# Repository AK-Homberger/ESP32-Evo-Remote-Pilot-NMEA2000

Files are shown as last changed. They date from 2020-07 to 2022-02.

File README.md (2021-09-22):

# ESP32 Evolution Remote Pilot NMEA2000
This is a Remote Control for an Evolution EV-1 Auto Pilot via NMEA2000 (SeaTalk-NG).

It is based on the work of this project in GitHub: https://github.com/matztam/raymarine-evo-pilot-remote.
Many thanks for all the work to identify the NMEA 2000 codes for the EV-1 Course Computer.

The hardware consists of an ESP32 NodeMCU (here from AZ-Delivery), a CAN bus transceiver, a 433MHz receiver (RXB6) and a power converter.
Thats's all what is required to control an EV-1 based Auto Pilot with a simple 433 MHz remote control.

A standard 4 button 433 MHz KeyFob is used to send (+1 / -1 degree) and (+10 / -10 degrees) course changes to the autopilot (Auto/Standby is optional and requires two more buttons or an additional KeyFob). An accustical feedback for each received key is provided with a piezo buzzer tone. I tried to use the alarm function of the MFD (as within the Seatalk remote control). But so far I was not successful to send any alarm PGN that generates an alarm on the MFD.

For questions/discussions regarding the project you can use the OpenBoatProjects area this [Sailing Forum](https://www.segeln-forum.de/board194-boot-technik/board35-elektrik-und-elektronik/board195-open-boat-projects-org/77895-evo-autopilot-fernbedienung-mit-nmea2000/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). 

It's a German Sailing Forum, but other languages (preferred English) are welcome.

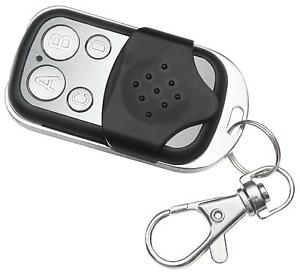
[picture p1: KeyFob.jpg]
KeyFob


The schmatics file and the [pcb details](https://github.com/AK-Homberger/ESP32-Evo-Remote-Pilot-NMEA2000/blob/master/ESP32EvoPilotRemotePCB.pdf) are in the KiCAD folder.
You can simply order a board from aisler.net: https://aisler.net/p/SXWTZTTS

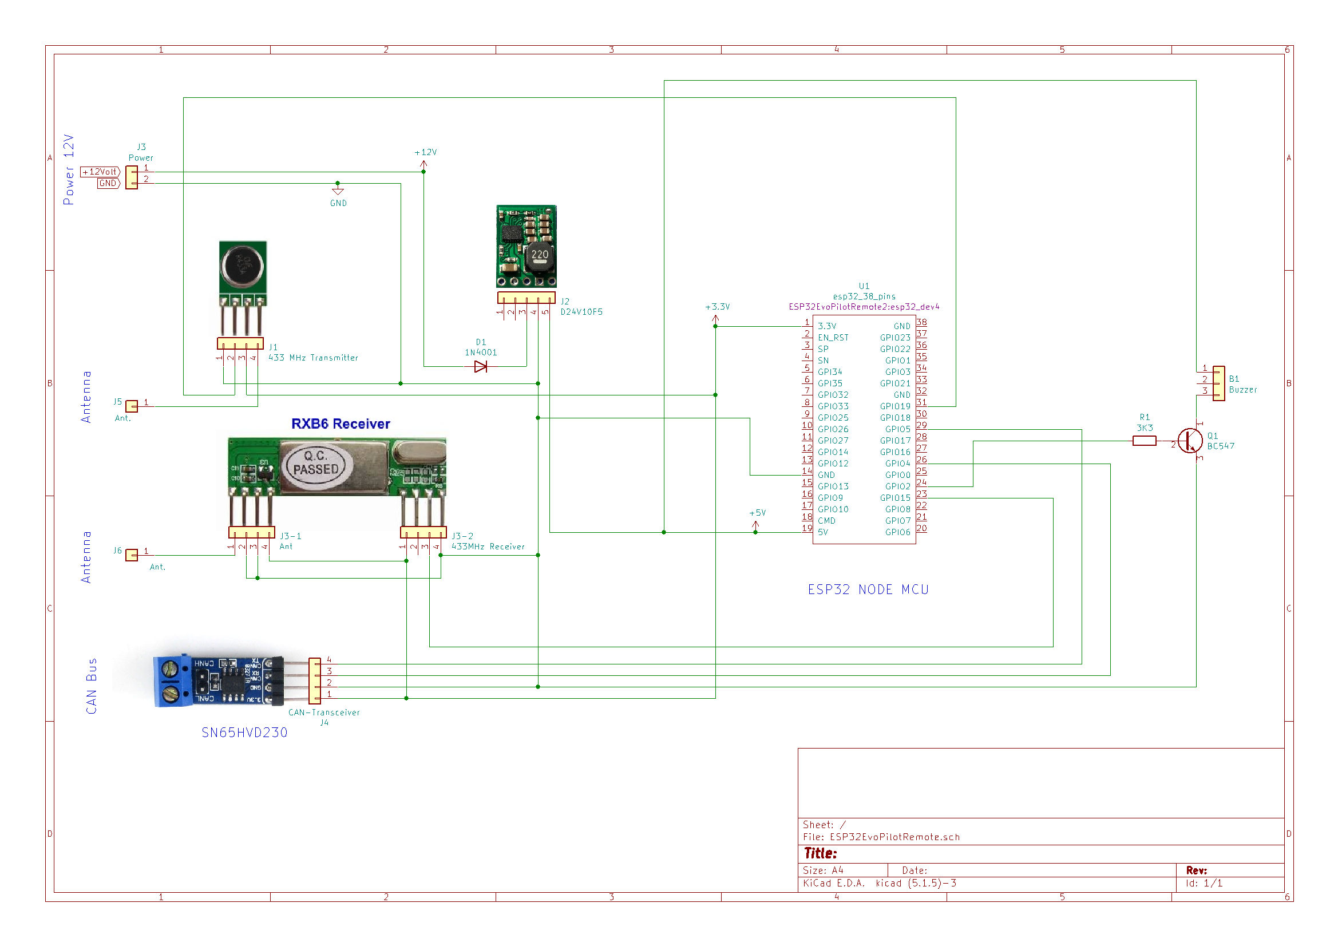
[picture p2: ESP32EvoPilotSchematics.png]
Schematics


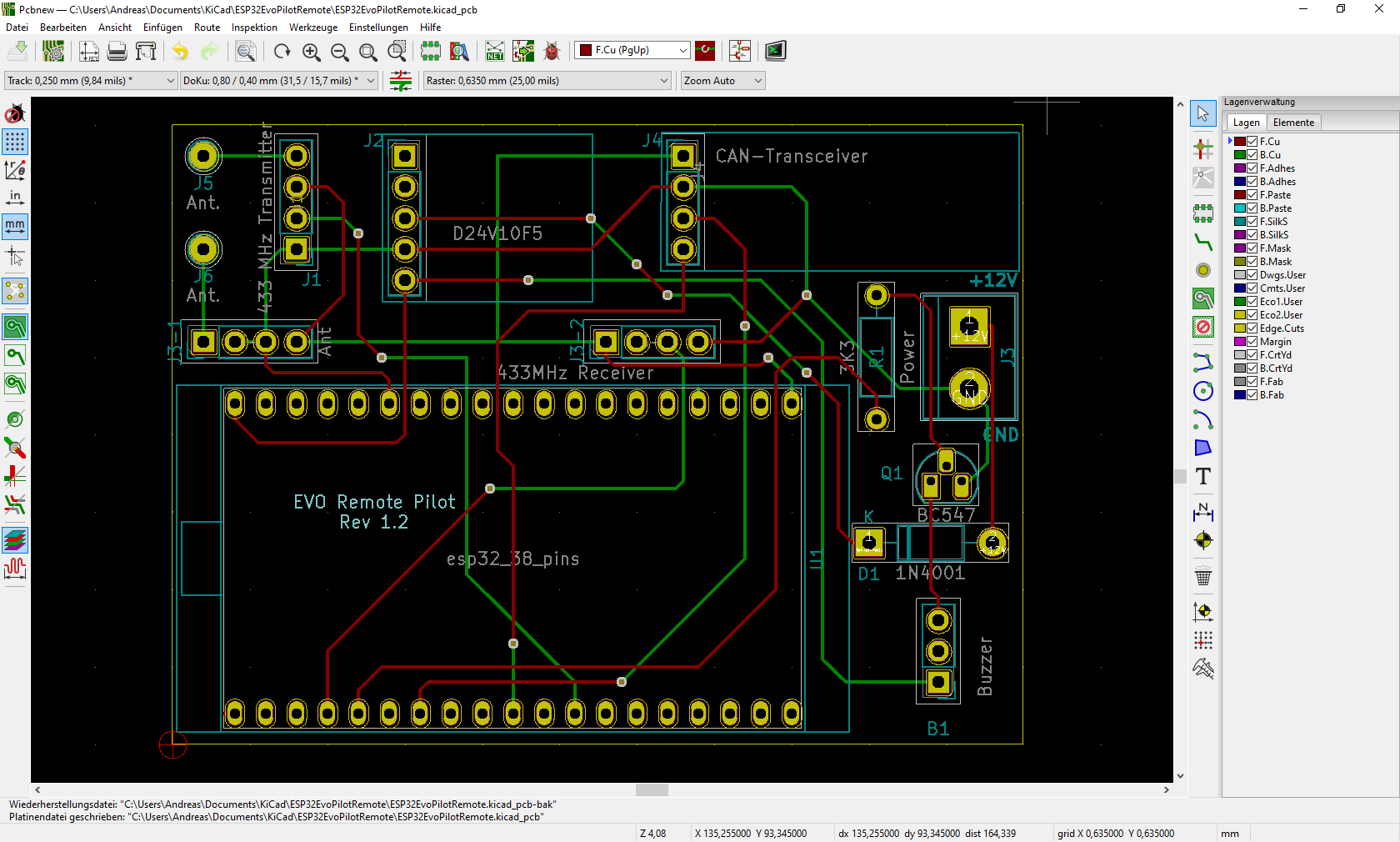
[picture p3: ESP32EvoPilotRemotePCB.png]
PCB


The code is using the NMEA 2000 libraries from Timo Lappalainen (https://github.com/ttlappalainen). 

Download and install the following libraries from GitHub link above:

 - NMEA2000
 - NMEA2000_esp32
 
The Remote Control is using the RCswitch library (to be installed with the Arduino IDE Library Manager).

For the ESP32 CAN bus, I use the "Waveshare SN65HVD230 Can Board" as transceiver. It works well with the ESP32 (GPIO pins 4 and 5). 
The 12 Volt is reduced to 5 Volt with a DC Step Down Converter (D24V10F5, https://www.pololu.com/product/2831).

GPIO 15 is used for the data from the RXB6 receiver. As antenna please use a short wire (e.g. 17,3 cm).
GPIO 2 is used to generate accustical feedback with a piezo buzzer.

# Programming the 433 MHz KeyFob

For programming the KeyFob please use the sketch ESP32_433_Programming.ino (https://github.com/AK-Homberger/ESP32-Evo-Remote-Pilot-NMEA2000/tree/master/ESP32_433_Programming). The Transmitter is connected to GPIO 19.

You should change the four codes in the software to individual random numbers. The same codes have to be copied to the programing sketch. 

Send each code individually and programm the keys of the remote according to the programming description of your KeyFob. Press "Send" button in serial console for next key. 

Key 1 = button A = -1 degree

Key 2 = button B =  +1 degree

Key 3 = button C = -10 degrees

Key 4 = button D = +10 degrees

If you use Auto/Standby function you also have to program the two additional buttons accordingly. After programming you can check directly if codes are programmed correctly. Just press the key on the remote and check if the shown value is correct.

It is possible to integrate the Remote Control code also in other ESP32 NMEA2000 projects (like the WiFi Gateway). But unfortunately the WLAN interfers with the 433 MHz receiver. Either RF part or interrupt for the RCSwitch). I noticed problems with the correct recognition of keys from the remote. As a result, I would suggest to avoid the integration in any other project with WLAN.

# Remove the 120 ohm resistor from the transceiver
For unknown reasons, many CAN bus transceivers for the ESP32 have a 120 Ohm resistor built into them. The resistor does not belong to the devices at the ends of the stub lines, but to the ends of the backbone cable.

Whether the transceiver contains a 120 ohm resistor can be determined either by looking at the [circuit diagram](https://github.com/AK-Homberger/NMEA2000-Workshop/blob/main/Docs/SN65HVD230%20CAN%20Board_SCH.pdf) or by measuring with the multimeter.

A knife tip is suitable for removing the SMD resistor. Use it to scratch or pry off the resistance. With the transceiver shown here, place the tip of the knife in front of the resistor (between the chip and the resistor) and support the knife against the chip. Then lever the tip against the resistance and use it to scratch / loosen / break the resistance. Whichever happens first.

Transceiver

It then looks like the picture. Then measure to be on the safe side. Without a 120 ohm resistor, the multimeter shows approx. 75 kOhm.

# Parts:

- Board (PCB) [Link](https://aisler.net/p/SXWTZTTS)
- ESP32 [Link](https://www.amazon.de/AZDelivery-NodeMCU-Development-Nachfolgermodell-ESP8266/dp/B071P98VTG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) 
- RXB6 433 MHz receiver [Link](https://www.makershop.de/en/module/funk/rxb6-433mhz-antenne/)
- SN65HVD230 [Link](https://eckstein-shop.de/WaveshareSN65HVD230CANTransceiverBoard33V2CESDProtection)
- D24V10F5 [Link](https://eckstein-shop.de/Pololu5V2C1AStep-DownSpannungsreglerD24V10F5)
- Buzzer [Link](https://www.reichelt.de/de/en/developer-boards-active-piezo-buzzer-module-debo-piezo-p239111.html?&nbc=1)
- Resistor 3,3 KOhm [Link](https://www.reichelt.de/de/en/carbon-film-resistor-1-4-w-5-3-3-kohm-1-4w-3-3k-p1397.html?&nbc=1)
- Transistor BC547 [Link](https://www.reichelt.de/bipolartransistor-npn-45v-0-1a-0-5w-to-92-bc-547b-dio-p219082.html?search=BC547)
- Connector 2-pin [Link](https://www.reichelt.de/de/en/2-pin-terminal-strip-spacing-5-08-akl-101-02-p36605.html?&nbc=1)

For programming:
433MHz transmitter [Link](https://www.digikey.de/product-detail/de/sparkfun-electronics/WRL-10534/1568-1175-ND/5673761) or [Link2](https://www.makershop.de/en/module/funk/433-sender-empfaenger/). The second one has only internal antenna.

Remote Control (KeyFob):  [Link](https://www.amazon.de/XCSOURCE-Elektrische-Universal-Garagentor-Fernbedienung-Ersatz-Schl%C3%BCsselanh%C3%A4nger-HS641/dp/B01KJRGMHI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) or [Link2](https://www.amazon.de/EasyULT-Handsender-Fernbedienung-Automatische-Garagentor%C3%B6ffner/dp/B0829WXGR5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) or [Link3](https://de.aliexpress.com/item/4000850169472.html?spm=a2g0s.9042311.0.0.15244c4dubWD35)

# Updates
- Version 0.7, 29.08.2021: Switch off WiFi and BT completely.

- Version 0.6, 16.12.2020: Changed PCB layout to Rev 1.2. Corrected orientation of ESP32 (USB connector to outside).

- Version 0.5, 05.11.2020: Changed PCB layout to Rev 1.1. Bigger terminal block (5.08 mm) and different transitor footprint for easy soldering.

- Version 0.5, 30.10.2020: Added KiCAD files and PCB. 

- Version 0.5, 25.09.2020: Changed BeepOn() in code to generate beep even if no EV-1 device is found (to alow testing). 

- Version 0.4, 04.08.2020: Changed TX pin from 2 to 5. Addedd buzzer to pin 2. Store/restore last used NodeAddress.

- Version 0.2, 26.07.2020: Avoid using delay(), added SetN2kPGN65361 (Seatalk Alarm State) to allow alarm beep for key received feedback.

- Version 0.1, 24.07.2020: Initial version.

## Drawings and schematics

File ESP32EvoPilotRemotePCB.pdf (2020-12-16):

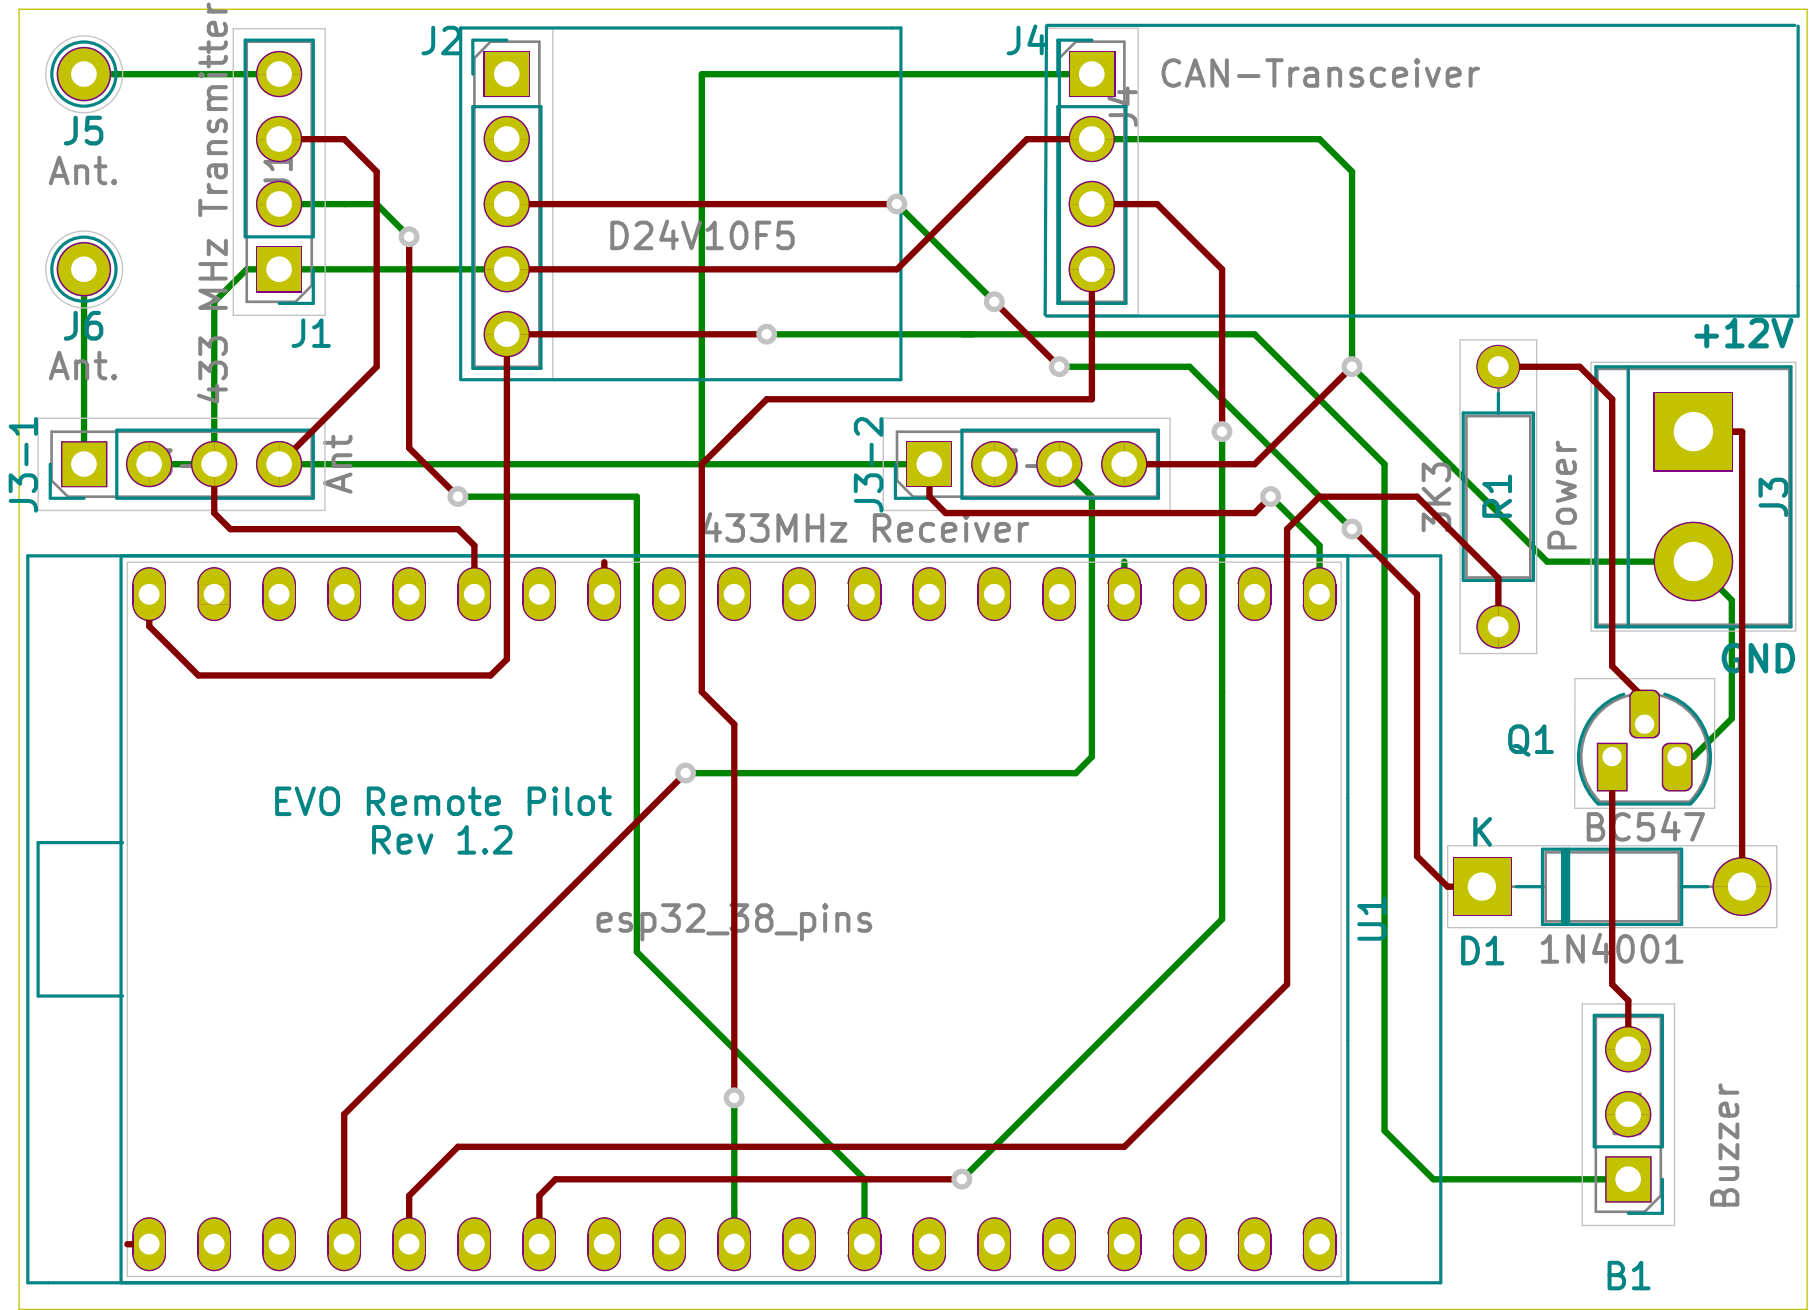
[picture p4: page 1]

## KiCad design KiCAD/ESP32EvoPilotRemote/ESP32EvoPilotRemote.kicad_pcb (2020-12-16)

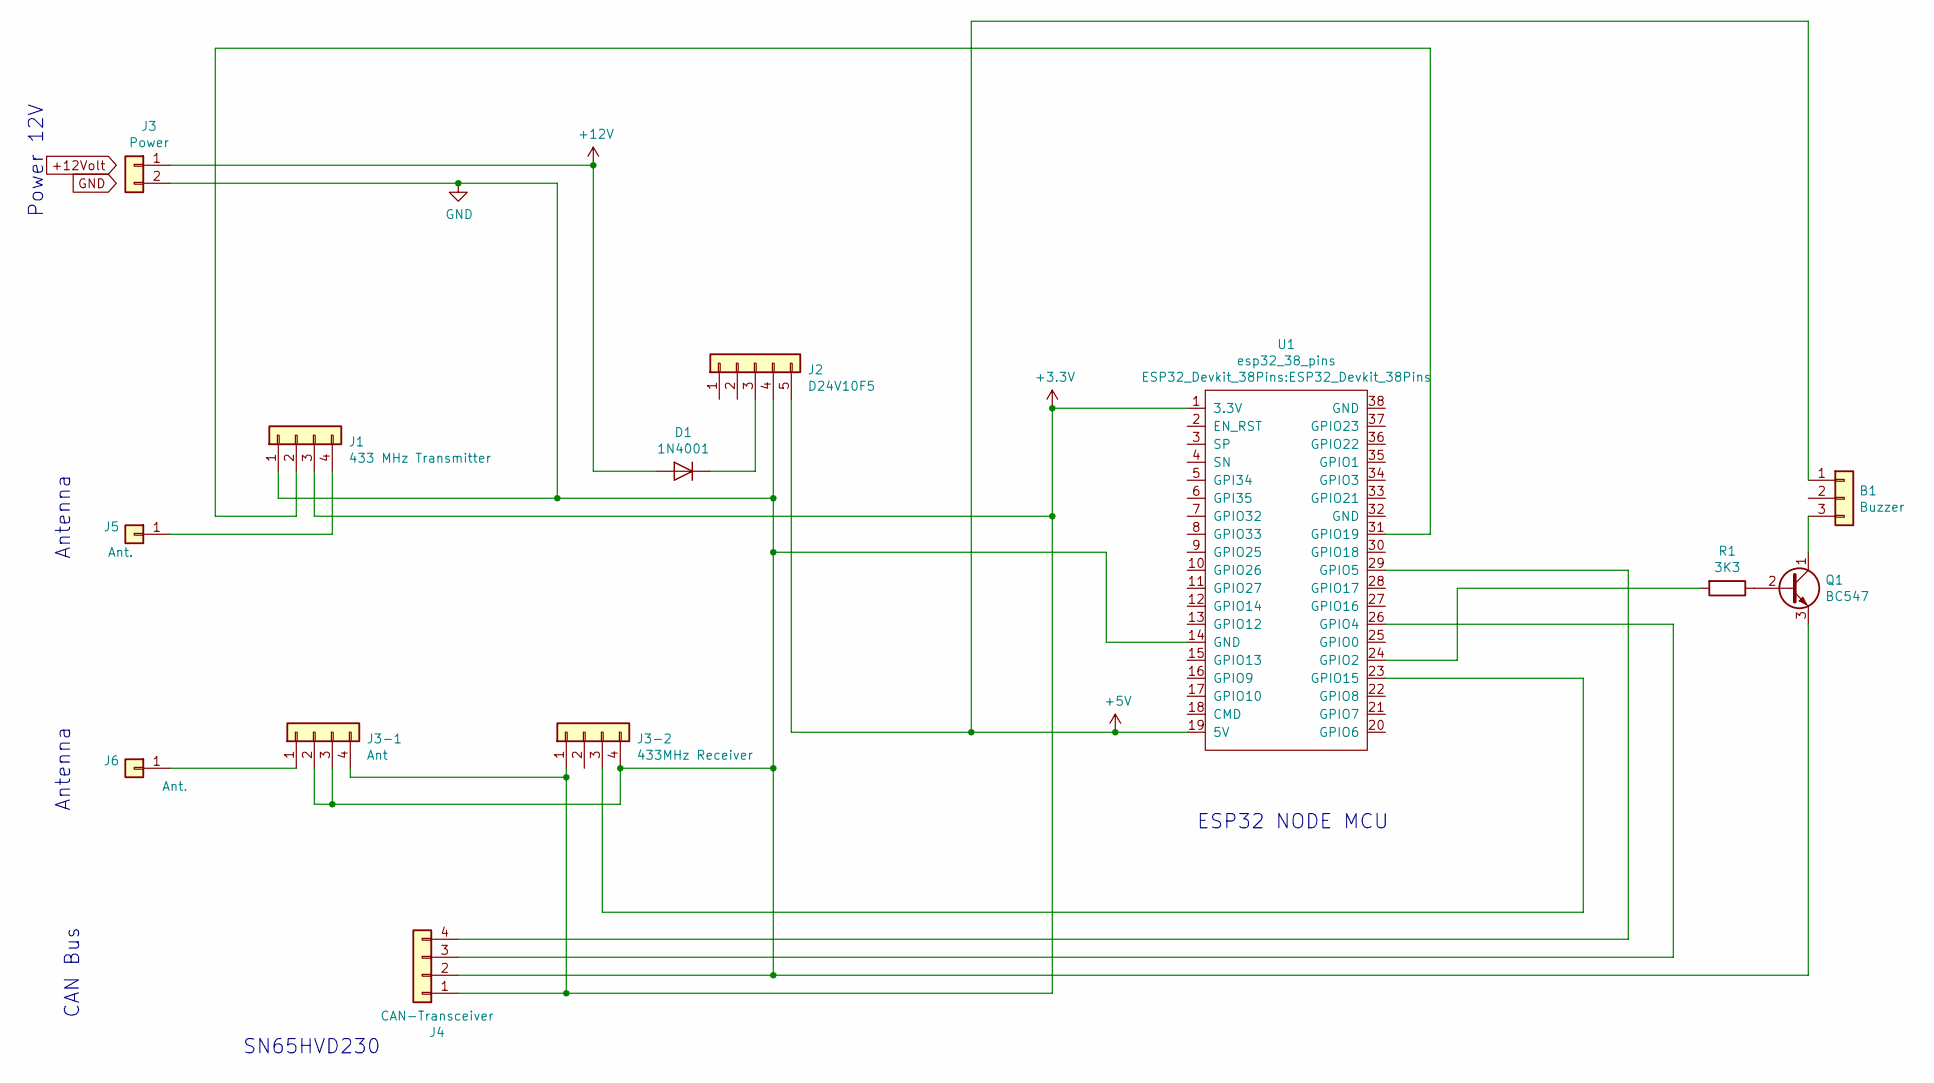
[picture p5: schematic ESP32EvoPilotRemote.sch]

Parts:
B1: Buzzer; PinHeader_1x03_P2.54mm_Vertical
D1: 1N4001; D_DO-41_SOD81_P10.16mm_Horizontal
J1: 433 MHz Transmitter; PinHeader_1x04_P2.54mm_Vertical
J2: D24V10F5; PinHeader_1x05_P2.54mm_Vertical
J3: Power; TerminalBlock_bornier-2_P5.08mm
J3-1: Ant; PinHeader_1x04_P2.54mm_Vertical
J3-2: 433MHz Receiver; PinHeader_1x04_P2.54mm_Vertical
J4: CAN-Transceiver; PinHeader_1x04_P2.54mm_Vertical
J5, J6: Ant.; Pin_D1.0mm_L10.0mm
Q1: BC547; TO-92_HandSolder
R1: 3K3; R_Axial_DIN0207_L6.3mm_D2.5mm_P10.16mm_Horizontal
U1: esp32_38_pins; ESP32_Devkit_38Pins

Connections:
+3V3: J1.3, J3-1.4, J3-2.1, J4.1, U1.1 (3.3V)
+5V: B1.1, J2.5, U1.19 (5V)
+12V: D1.2 (A), J3.1
GND: J1.1, J2.4, J3.2, J3-1.2, J3-1.3, J3-2.4, J4.2, Q1.3 (E), U1.14 (GND)
unnamed: B1.3, Q1.1 (C)
unnamed: D1.1 (K), J2.3
unnamed: J1.2, U1.31 (GPIO19)
unnamed: J1.4, J5.1
unnamed: J3-1.1, J6.1
unnamed: J3-2.3, U1.23 (GPIO15)
unnamed: J4.3, U1.26 (GPIO4)
unnamed: J4.4, U1.29 (GPIO5)
unnamed: Q1.2 (B), R1.1
unnamed: R1.2, U1.24 (GPIO2)

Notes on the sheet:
ESP32 NODE MCU
SN65HVD230
CAN Bus
Power 12V
Antenna

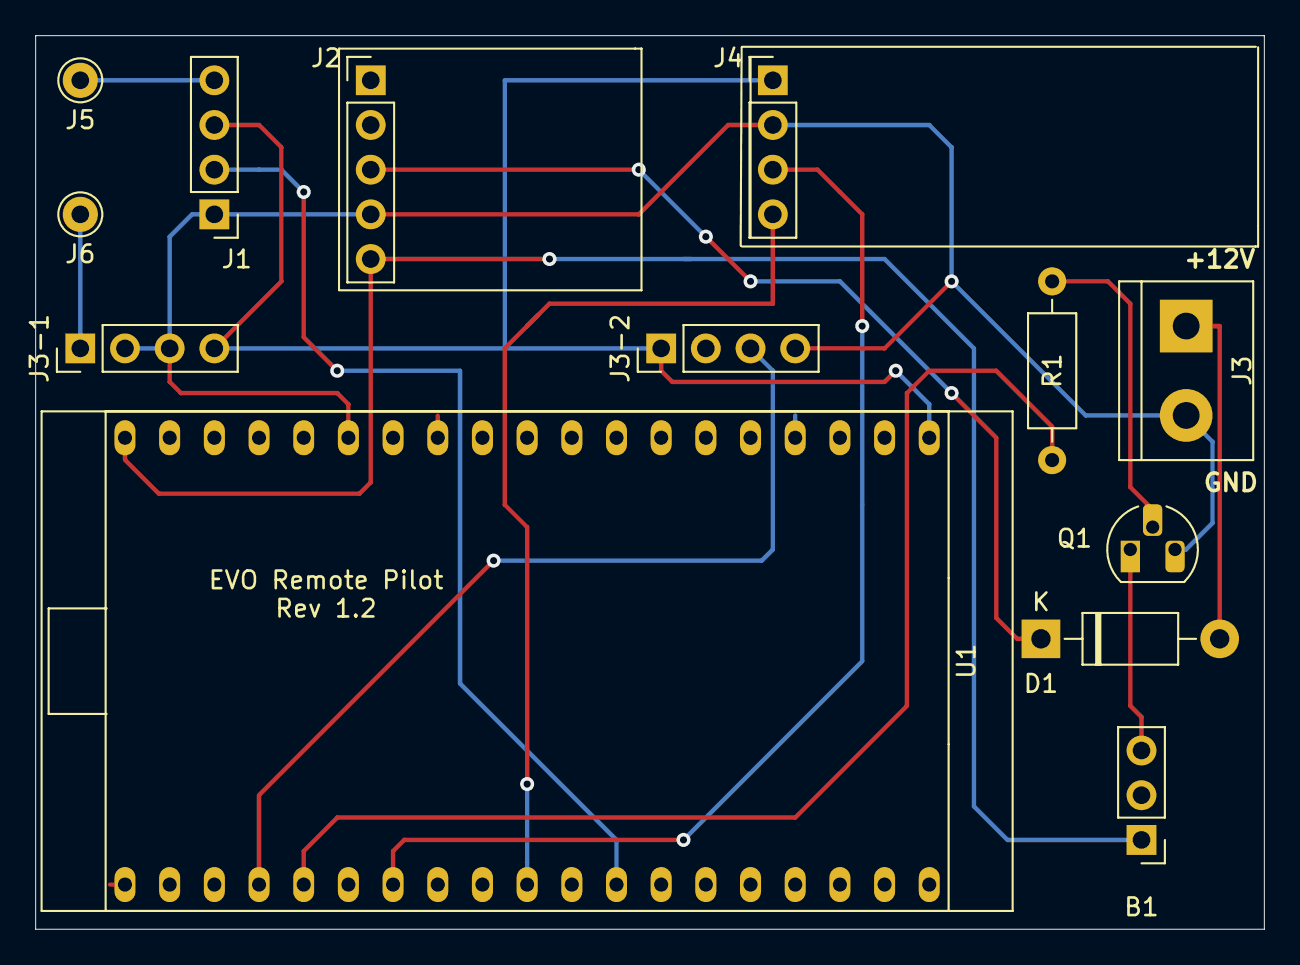
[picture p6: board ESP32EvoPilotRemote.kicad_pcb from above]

Board: 2 copper layers, 69.8 x 50.8 mm, 13 parts (0 on the bottom side), 14 nets.

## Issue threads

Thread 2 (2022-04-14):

EV-100 not found on ng network

thomasnisole, 2022-04-14:
Hello @AK-Homberger ,

I reproduced your remote system for my Pilot (ACU 200 / EV-100 / P70) on my boat, but i have some trouble with the search of the EV-100. When the ESP32 is connected on the bus, it don't find any EV-100 system.

To get as close as possible to the final assembly and avoid any disturbance, I do not use the USB output of the ESP32, I have installed different colored LEDs on the outputs of the ESP32 in order to know when the sketch has a problem.

Do you have any idea where it could be coming from. I take some picture of P70 diagnostic tool, here data from EV-100 :
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

Thank you for your reply.

Thomas.

AK-Homberger, 2022-04-14:
Hi Thomas,

Is the ESP32 shown in the device list in the MFD? If not then there is a problem with your program or with the hardware.

Can you share your modified program. Then I will have a look.

Regards,
Andreas

thomasnisole, 2022-04-14:
Hi @AK-Homberger ,

Yes my code is in a [github repository](https://github.com/thomasnisole/ESP32-Evo-Remote-Pilot-NMEA2000), i forked yours to save my remote buttons values :)

Et pour répondre à ta question, non mon ESP32 n'est pas visible dans la liste MFD du P70. For CAN interface, i use this [shield](https://www.ebay.fr/itm/294171691651?ssPageName=STRK%3AMEBIDX%3AIT&_trksid=p2060353.m2749.l2649).
I cut R2 to have 60ohms between L and H when device is connected to NG CAN. I can take a picture of my wiring if you want.

Thank you.

AK-Homberger, 2022-04-14:
Hi Thomas,

That will not work. You can't use a delay() in the below function:

void messageSent() {
  digitalWrite(MESSAGE_SENDET_PIN, HIGH);
  delay(1000);
  digitalWrite(MESSAGE_SENDET_PIN, LOW);
}

It will block the whole processing. First try without a dalay and the if ot is working do the delay with a millis() construction.

Regards,
Andreas

thomasnisole, 2022-04-14:
Hi @AK-Homberger ,

I removed usage of delay function in loop scope, but P70 does not found ESP32 in diagnostic tool.

Thank you.

AK-Homberger, 2022-04-15:
Then it's probably a problem with the hardware. Did you check if the program is running ata all?
E.g. with additional Serial.print() statements in setup()?

thomasnisole, 2022-04-15:
Hi @AK-Homberger ,

Last night I added a log at the very beginning of the function `getDeviceSourceAddress`, and I never go through the for loop, I exit with the return -1.

Here is the stack trace :

```
rst:0x1 (POWERON_RESET),boot:0x12 (SPI_FAST_FLASH_BOOT)
configsip: 0, SPIWP:0xee
clk_drv:0x00,q_drv:0x00,d_drv:0x00,cs0_drv:0x00,hd_drv:0x00,wp_drv:0x00
mode:DIO, clock div:1
load:0x3fff0018,len:4
load:0x3fff001c,len:1216
ho 0 tail 12 room 4
load:0x40078000,len:10944
load:0x40080400,len:6388
entry 0x400806b4
NodeAddress=34
NMEA2000 Open
getDeviceSourceAddress
getDeviceSourceAddress
...
```

AK-Homberger, 2022-04-15:
getDeviceSourceAddress() has to exit with the address of the found device. Perhaps Raymarine changed the model string from "EV1" to "EV-1 Course Computer".

Please add a Serial output to the getDeviceSourceAddress() function to get all found device names:
...
String modelVersion = device->GetModelVersion();
Serial.println(modelVersion);
...

thomasnisole, 2022-05-23:
Hello @AK-Homberger ,

I finally bought the same component which you used, and good news, it's working !! I can see the remote controller into p70 diagnostic tool !
Thank you so much for your work, i will go to update your Kicad files to add some screw hole to add a step down voltage like this [one](https://www.ebay.fr/itm/133424784191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) to fix it above your D24V10F5 (I can't find it in fast delivery from France).

Thank you for your help !

Thomas.

Closed 2023-05-17.

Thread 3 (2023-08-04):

Combine with cheap rf receiver and remote

Fietsenwiel, 2023-08-04:
I think it is easier when you would use a cheap rf receiver with a remote rather than program your own remote with a rf reiceiver and transmitter.

This way you can easily replace the remote for any onther one when you lose one.
The cheap receivers already have a way to learn the new remote.
This way you also can use more than one remote at the same time (for spare).

I added some code to make this possible by adding fysicale buttons whicht can be connected to the chaep rf receiver
Also I added short and long presses, the long presses for Auto and Standby:

`/*
  This code is free software; you can redistribute it and/or
  modify it under the terms of the GNU Lesser General Public
  License as published by the Free Software Foundation; either
  version 2.1 of the License, or (at your option) any later version.
  This code is distributed in the hope that it will be useful,
  but WITHOUT ANY WARRANTY; without even the implied warranty of
  MERCHANTABILITY or FITNESS FOR A PARTICULAR PURPOSE.  See the GNU
  Lesser General Public License for more details.
  You should have received a copy of the GNU Lesser General Public
  License along with this library; if not, write to the Free Software
  Foundation, Inc., 51 Franklin St, Fifth Floor, Boston, MA  02110-1301  USA
*/

// NMEA2000 Remote Control for EV-1
//   - Reads 433 MHz commands via RXB6 receiver
//   - Sends NMEA2000 messages to EV-1 Course Computer

// Version 0.7, 29.08.2021, AK-Homberger

// Code added for four fysical keys. Auto and standby can be set by long presses.
// The pins for the fysical keys can be connected to a cheap rf receiver with a remote control
// This way it is easy to replace any remote by learning the remote with the cheap receiver.

#define ESP32_CAN_TX_PIN GPIO_NUM_5  // Set CAN TX port to 5
#define ESP32_CAN_RX_PIN GPIO_NUM_4  // Set CAN RX port to 4

#include <Arduino.h>
#include <WiFi.h>
#include <Preferences.h>
#include <N2kMsg.h>
#include <NMEA2000.h>
#include <NMEA2000_CAN.h>
#include <RCSwitch.h>

#include "RaymarinePilot.h"
#include "N2kDeviceList.h"

#define ESP32_RCSWITCH_PIN GPIO_NUM_15  // Set RCSWITCH port to 15 (RXB6 receiver)
#define KEY_DELAY 300  // 300 ms break between keys
#define BEEP_TIME 200  // 200 ms beep time

#define BUZZER_PIN 2  // Buzzer connected to GPIO 2

int NodeAddress;  // To store last Node Address

Preferences preferences;             // Nonvolatile storage on ESP32 - To store LastDeviceAddress

RCSwitch mySwitch = RCSwitch();

unsigned long key_time = 0;
unsigned long beep_time = 0;
bool beep_status = false;

const unsigned long Key_Minus_1 = 1111001; // Change values to individual values programmed to remote control
const unsigned long Key_Plus_1 = 1111002;
const unsigned long Key_Minus_10 = 1111003;
const unsigned long Key_Plus_10 = 1111004;
const unsigned long Key_Auto = 1111005;
const unsigned long Key_Standby = 1111006;

const unsigned long TransmitMessages[] PROGMEM = {126208UL,   // Set Pilot Mode
                                                  126720UL,   // Send Key Command
                                                  65288UL,    // Send Seatalk Alarm State
                                                  0
                                                 };

const unsigned long ReceiveMessages[] PROGMEM = { 127250UL,   // Read Heading
                                                  65288UL,    // Read Seatalk Alarm State
                                                  65379UL,    // Read Pilot Mode
                                                  0
                                                };
				
//Init for adding fysical key's
const int BUTTON_PIN_Min1 = 21; // "-1"
const int BUTTON_PIN_Plus1 = 20; // "+1"
const int BUTTON_PIN_Min10 = 19; // "-10" long = Auto
const int BUTTON_PIN_Plus10 = 18; // "+10" long = Standby
const int SHORT_PRESS_TIME_Auto = 700; // 700 milliseconds "A"
const int SHORT_PRESS_TIME_Standby = 700; // 700 milliseconds "S"
// Variables will change:
int lastState_Plus1 = LOW;  // the previous state from the input pin
int currentState_Plus1;     // the current reading from the input pin
int lastState_Min1 = LOW;  // the previous state from the input pin
int currentState_Min1;     // the current reading from the input pin
int lastState_Min10 = LOW;  // the previous state from the input pin
int currentState_Min10;     // the current reading from the input pin
unsigned long pressedTime_Min10  = 0;
unsigned long releasedTime_Min10 = 0;
int lastState_Plus10 = LOW;  // the previous state from the input pin
int currentState_Plus10;     // the current reading from the input pin
unsigned long pressedTime_Plus10  = 0;
unsigned long releasedTime_Plus10 = 0;
//End init for adding fysical key's

tN2kDeviceList *pN2kDeviceList;
short pilotSourceAddress = -1;

void setup() {
  uint8_t chipid[6];
  uint32_t id = 0;
  int i = 0;

  WiFi.mode(WIFI_OFF);
  btStop();

  esp_efuse_mac_get_default(chipid);
  for (i = 0; i < 6; i++) id += (chipid[i] << (7 * i));

  // Reserve enough buffer for sending all messages. This does not work on small memory devices like Uno or Mega
  NMEA2000.SetN2kCANReceiveFrameBufSize(150);
  NMEA2000.SetN2kCANMsgBufSize(8);
  // Set Product information
  NMEA2000.SetProductInformation("00000001", // Manufacturer's Model serial code
                                 100, // Manufacturer's product code
                                 "Evo Pilot Remote",  // Manufacturer's Model ID
                                 "1.0.0.0",  // Manufacturer's Software version code
                                 "1.0.0.0" // Manufacturer's Model version
                                );
  // Set device information
  NMEA2000.SetDeviceInformation(id, // Unique number. Use e.g. Serial number.
                                132, // Device function=Analog to NMEA 2000 Gateway. See codes on http://www.nmea.org/Assets/20120726%20nmea%202000%20class%20&%20function%20codes%20v%202.00.pdf
                                25, // Device class=Inter/Intranetwork Device. See codes on  http://www.nmea.org/Assets/20120726%20nmea%202000%20class%20&%20function%20codes%20v%202.00.pdf
                                2046 // Just choosen free from code list on http://www.nmea.org/Assets/20121020%20nmea%202000%20registration%20list.pdf
                               );

  Serial.begin(115200);
  delay(100);

  pinMode(BUZZER_PIN, OUTPUT);
  //Definition for adding fysical key's
  pinMode(BUTTON_PIN_Min1, INPUT_PULLUP);
  pinMode(BUTTON_PIN_Plus1, INPUT_PULLUP);
  pinMode(BUTTON_PIN_Min10, INPUT_PULLUP);
  pinMode(BUTTON_PIN_Plus10, INPUT_PULLUP);
  //End definition for adding fysical key's
  digitalWrite(BUZZER_PIN, LOW);

  mySwitch.enableReceive(ESP32_RCSWITCH_PIN);  // Receiver on GPIO15 on ESP32

  // Uncomment 3 rows below to see, what device will send to bus
  //NMEA2000.SetForwardStream(&Serial);  // PC output on due programming port
  //NMEA2000.SetForwardType(tNMEA2000::fwdt_Text); // Show in clear text. Leave uncommented for default Actisense format.
  //NMEA2000.SetForwardOwnMessages();

  preferences.begin("nvs", false);                          // Open nonvolatile storage (nvs)
  NodeAddress = preferences.getInt("LastNodeAddress", 34);  // Read stored last NodeAddress, default 34
  preferences.end();
  Serial.printf("NodeAddress=%d\n", NodeAddress);

  // If you also want to see all traffic on the bus use N2km_ListenAndNode instead of N2km_NodeOnly below
  NMEA2000.SetMode(tNMEA2000::N2km_NodeOnly, NodeAddress); //N2km_NodeOnly N2km_ListenAndNode
  NMEA2000.ExtendTransmitMessages(TransmitMessages);
  NMEA2000.ExtendReceiveMessages(ReceiveMessages);

  NMEA2000.SetMsgHandler(RaymarinePilot::HandleNMEA2000Msg);

  pN2kDeviceList = new tN2kDeviceList(&NMEA2000);
  //NMEA2000.SetDebugMode(tNMEA2000::dm_ClearText); // Uncomment this, so you can test code without CAN bus chips on Arduino Mega
  NMEA2000.EnableForward(false); // Disable all msg forwarding to USB (=Serial)
  NMEA2000.Open();

  Serial.println((String) "NMEA2000 Open");

}

// Beep on if key received

void BeepOn() {
  if (beep_status == true) return;  // Already On

  digitalWrite(BUZZER_PIN, HIGH);
  beep_time = millis();
  beep_status = true;
}

// Beep off after BEEP_TIME

void BeepOff() {
  if (beep_status == true && millis() > beep_time + BEEP_TIME) {
    digitalWrite(BUZZER_PIN, LOW);
    beep_status = false;
  }
}

// Get device source address (of EV-1)

int getDeviceSourceAddress(String model) {
  if (!pN2kDeviceList->ReadResetIsListUpdated()) return -1;
  for (uint8_t i = 0; i < N2kMaxBusDevices; i++) {
    const tNMEA2000::tDevice *device = pN2kDeviceList->FindDeviceBySource(i);
    if ( device == 0 ) continue;

    String modelVersion = device->GetModelVersion();

    if (modelVersion.indexOf(model) >= 0) {
      return device->GetSource();
    }
  }
  return -2;
}

// Receive 433 MHz commands from remote and send SeatalkNG codes to EV-1 (if available)

void Handle_AP_Remote(void) {
  unsigned long key = 0;

  if (pilotSourceAddress < 0) pilotSourceAddress = getDeviceSourceAddress("EV-1"); // Try to get EV-1 Source Address

  if (mySwitch.available()) {
    key = mySwitch.getReceivedValue();
    mySwitch.resetAvailable();
  }

  //Code for adding fysical key's
  //*******************read if key is pressed
  // *** MIN 1 *** read the state of the Min 1 input: Short press is -1
  currentState_Min1 = digitalRead(BUTTON_PIN_Min1);
  if(lastState_Min1 == HIGH && currentState_Min1 == LOW)        // button is pressed
        Serial.println("Press -1 is detected");
		stringComplete = true;
		inputString = "-1";
  // save the the last state
   lastState_Min1 = currentState_Min1;
  // *** MIN 1 *****  end of read the state of the Min 1 input

  // *** Plus 1 ***** read the state of the Plus 1 input: Short press is +1
  currentState_Plus1 = digitalRead(BUTTON_PIN_Plus1);
  if(lastState_Plus1 == HIGH && currentState_Plus1 == LOW)        // button is pressed
        Serial.println("Press +1 is detected");
		stringComplete = true;
		inputString = "+1";      //value = Key_Plus_1;
  // save the the last state
   lastState_Plus1 = currentState_Plus1;
  // ***PLUS 1 *****  end of read the state of the Min 1 input

  // *** MIN 10 en Auto **********8read the state of the Min 10 input: Short press is -10, long press is Auto
  currentState_Min10 = digitalRead(BUTTON_PIN_Min10);
  if(lastState_Min10 == HIGH && currentState_Min10 == LOW)        // button is pressed
    pressedTime_Min10 = millis();
  else if(lastState_Min10 == LOW && currentState_Min10 == HIGH) { // button is released
		stringComplete = true;
		releasedTime_Min10 = millis();
    long pressDuration_Min10 = releasedTime_Min10 - pressedTime_Min10;
    if( pressDuration_Min10 < SHORT_PRESS_TIME_Auto ){
      Serial.println("Press -10 is detected");
  		inputString = "-10";      //value = Key_Plus_1;
		//value = Key_Minus_10;
    }
	  else {
	    Serial.println("Press A is detected");
		  inputString = "A";      //value = Key_Plus_1;
		  //value = Key_Auto;
	  }
  }
  // save the the last state
  lastState_Min10 = currentState_Min10;
  // *** MIN 10 en Auto ***** end of read the state of the Min 10 input
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

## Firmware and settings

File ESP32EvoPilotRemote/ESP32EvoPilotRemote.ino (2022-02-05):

/*
  This code is free software; you can redistribute it and/or
  modify it under the terms of the GNU Lesser General Public
  License as published by the Free Software Foundation; either
  version 2.1 of the License, or (at your option) any later version.
  This code is distributed in the hope that it will be useful,
  but WITHOUT ANY WARRANTY; without even the implied warranty of
  MERCHANTABILITY or FITNESS FOR A PARTICULAR PURPOSE.  See the GNU
  Lesser General Public License for more details.
  You should have received a copy of the GNU Lesser General Public
  License along with this library; if not, write to the Free Software
  Foundation, Inc., 51 Franklin St, Fifth Floor, Boston, MA  02110-1301  USA
*/

// NMEA2000 Remote Control for EV-1
//   - Reads 433 MHz commands via RXB6 receiver
//   - Sends NMEA2000 messages to EV-1 Course Computer

// Version 0.7, 29.08.2021, AK-Homberger

#define ESP32_CAN_TX_PIN GPIO_NUM_5  // Set CAN TX port to 5 
#define ESP32_CAN_RX_PIN GPIO_NUM_4  // Set CAN RX port to 4

#include <Arduino.h>
#include <WiFi.h>
#include <Preferences.h>
#include <N2kMsg.h>
#include <NMEA2000.h>
#include <NMEA2000_CAN.h>
#include <RCSwitch.h>

#include "RaymarinePilot.h"
#include "N2kDeviceList.h"

#define ESP32_RCSWITCH_PIN GPIO_NUM_15  // Set RCSWITCH port to 15 (RXB6 receiver)
#define KEY_DELAY 300  // 300 ms break between keys
#define BEEP_TIME 200  // 200 ms beep time

#define BUZZER_PIN 2  // Buzzer connected to GPIO 2

int NodeAddress;  // To store last Node Address

Preferences preferences;             // Nonvolatile storage on ESP32 - To store LastDeviceAddress

RCSwitch mySwitch = RCSwitch();

unsigned long key_time = 0;
unsigned long beep_time = 0;
bool beep_status = false;

const unsigned long Key_Minus_1 = 1111001; // Change values to individual values programmed to remote control
const unsigned long Key_Plus_1 = 1111002;
const unsigned long Key_Minus_10 = 1111003;
const unsigned long Key_Plus_10 = 1111004;
const unsigned long Key_Auto = 1111005;
const unsigned long Key_Standby = 1111006;

const unsigned long TransmitMessages[] PROGMEM = {126208UL,   // Set Pilot Mode
                                                  126720UL,   // Send Key Command
                                                  65288UL,    // Send Seatalk Alarm State
                                                  0
                                                 };

const unsigned long ReceiveMessages[] PROGMEM = { 127250UL,   // Read Heading
                                                  65288UL,    // Read Seatalk Alarm State
                                                  65379UL,    // Read Pilot Mode
                                                  0
                                                };

tN2kDeviceList *pN2kDeviceList;
short pilotSourceAddress = -1;


void setup() {
  uint8_t chipid[6];
  uint32_t id = 0;
  int i = 0;
  
  WiFi.mode(WIFI_OFF);
  btStop();

  esp_efuse_mac_get_default(chipid);
  for (i = 0; i < 6; i++) id += (chipid[i] << (7 * i));

  // Reserve enough buffer for sending all messages. This does not work on small memory devices like Uno or Mega
  NMEA2000.SetN2kCANReceiveFrameBufSize(150);
  NMEA2000.SetN2kCANMsgBufSize(8);
  // Set Product information
  NMEA2000.SetProductInformation("00000001", // Manufacturer's Model serial code
                                 100, // Manufacturer's product code
                                 "Evo Pilot Remote",  // Manufacturer's Model ID
                                 "1.0.0.0",  // Manufacturer's Software version code
                                 "1.0.0.0" // Manufacturer's Model version
                                );
  // Set device information
  NMEA2000.SetDeviceInformation(id, // Unique number. Use e.g. Serial number.
                                132, // Device function=Analog to NMEA 2000 Gateway. See codes on http://www.nmea.org/Assets/20120726%20nmea%202000%20class%20&%20function%20codes%20v%202.00.pdf
                                25, // Device class=Inter/Intranetwork Device. See codes on  http://www.nmea.org/Assets/20120726%20nmea%202000%20class%20&%20function%20codes%20v%202.00.pdf
                                2046 // Just choosen free from code list on http://www.nmea.org/Assets/20121020%20nmea%202000%20registration%20list.pdf
                               );

  Serial.begin(115200);
  delay(100);

  pinMode(BUZZER_PIN, OUTPUT);
  digitalWrite(BUZZER_PIN, LOW);

  mySwitch.enableReceive(ESP32_RCSWITCH_PIN);  // Receiver on GPIO15 on ESP32

  // Uncomment 3 rows below to see, what device will send to bus
  //NMEA2000.SetForwardStream(&Serial);  // PC output on due programming port
  //NMEA2000.SetForwardType(tNMEA2000::fwdt_Text); // Show in clear text. Leave uncommented for default Actisense format.
  //NMEA2000.SetForwardOwnMessages();

  preferences.begin("nvs", false);                          // Open nonvolatile storage (nvs)
  NodeAddress = preferences.getInt("LastNodeAddress", 34);  // Read stored last NodeAddress, default 34
  preferences.end();
  Serial.printf("NodeAddress=%d\n", NodeAddress);

  // If you also want to see all traffic on the bus use N2km_ListenAndNode instead of N2km_NodeOnly below
  NMEA2000.SetMode(tNMEA2000::N2km_NodeOnly, NodeAddress); //N2km_NodeOnly N2km_ListenAndNode
  NMEA2000.ExtendTransmitMessages(TransmitMessages);
  NMEA2000.ExtendReceiveMessages(ReceiveMessages);

  NMEA2000.SetMsgHandler(RaymarinePilot::HandleNMEA2000Msg);

  pN2kDeviceList = new tN2kDeviceList(&NMEA2000);
  //NMEA2000.SetDebugMode(tNMEA2000::dm_ClearText); // Uncomment this, so you can test code without CAN bus chips on Arduino Mega
  NMEA2000.EnableForward(false); // Disable all msg forwarding to USB (=Serial)
  NMEA2000.Open();

  Serial.println((String) "NMEA2000 Open");
}


// Beep on if key received

void BeepOn() {
  if (beep_status == true) return;  // Already On

  digitalWrite(BUZZER_PIN, HIGH);
  beep_time = millis();
  beep_status = true;
}


// Beep off after BEEP_TIME

void BeepOff() {
  if (beep_status == true && millis() > beep_time + BEEP_TIME) {
    digitalWrite(BUZZER_PIN, LOW);
    beep_status = false;
  }
}


// Get device source address (of EV-1)

int getDeviceSourceAddress(String model) {
  if (!pN2kDeviceList->ReadResetIsListUpdated()) return -1;
  for (uint8_t i = 0; i < N2kMaxBusDevices; i++) {
    const tNMEA2000::tDevice *device = pN2kDeviceList->FindDeviceBySource(i);
    if ( device == 0 ) continue;

    String modelVersion = device->GetModelVersion();

    if (modelVersion.indexOf(model) >= 0) {
      return device->GetSource();
    }
  }
  return -2;
}


// Receive 433 MHz commands from remote and send SeatalkNG codes to EV-1 (if available)

void Handle_AP_Remote(void) {
  unsigned long key = 0;

  if (pilotSourceAddress < 0) pilotSourceAddress = getDeviceSourceAddress("EV-1"); // Try to get EV-1 Source Address

  if (mySwitch.available()) {
    key = mySwitch.getReceivedValue();
    mySwitch.resetAvailable();
  }

  if (key > 0 && millis() > key_time + KEY_DELAY) {
    key_time = millis();   // Remember time of last key received

    if (key == Key_Standby) {
      Serial.println("Setting PILOT_MODE_STANDBY");
      BeepOn();
      if (pilotSourceAddress < 0) return; // No EV-1 detected. Return!
      tN2kMsg N2kMsg;
      RaymarinePilot::SetEvoPilotMode(N2kMsg, pilotSourceAddress, PILOT_MODE_STANDBY);
      NMEA2000.SendMsg(N2kMsg);     
    }

    else if (key == Key_Auto) {
      Serial.println("Setting PILOT_MODE_AUTO");
      BeepOn();
      if (pilotSourceAddress < 0) return; // No EV-1 detected. Return!
      tN2kMsg N2kMsg;
      RaymarinePilot::SetEvoPilotMode(N2kMsg, pilotSourceAddress, PILOT_MODE_AUTO);
      NMEA2000.SendMsg(N2kMsg);      
    }

    else if (key == Key_Plus_1) {
      Serial.println("+1");
      BeepOn();
      if (pilotSourceAddress < 0) return; // No EV-1 detected. Return!
      tN2kMsg N2kMsg;
      RaymarinePilot::KeyCommand(N2kMsg, pilotSourceAddress, KEY_PLUS_1);
      NMEA2000.SendMsg(N2kMsg);
    }

    else if (key == Key_Plus_10) {
      Serial.println("+10");
      BeepOn();
      if (pilotSourceAddress < 0) return; // No EV-1 detected. Return!
      tN2kMsg N2kMsg;
      RaymarinePilot::KeyCommand(N2kMsg, pilotSourceAddress, KEY_PLUS_10);
      NMEA2000.SendMsg(N2kMsg);      
    }

    else if (key == Key_Minus_1) {
      Serial.println("-1");
      BeepOn();
      if (pilotSourceAddress < 0) return; // No EV-1 detected. Return!
      tN2kMsg N2kMsg;
      RaymarinePilot::KeyCommand(N2kMsg, pilotSourceAddress, KEY_MINUS_1);
      NMEA2000.SendMsg(N2kMsg);      
    }

    else if (key == Key_Minus_10) {
      Serial.println("-10");
      BeepOn();
      if (pilotSourceAddress < 0) return; // No EV-1 detected. Return!
      tN2kMsg N2kMsg;
      RaymarinePilot::KeyCommand(N2kMsg, pilotSourceAddress, KEY_MINUS_10);
      NMEA2000.SendMsg(N2kMsg);      
    }
  }
  BeepOff();
}


void loop() {
  Handle_AP_Remote();
  NMEA2000.ParseMessages();

  int SourceAddress = NMEA2000.GetN2kSource();
  if (SourceAddress != NodeAddress) { // Save potentially changed Source Address to NVS memory
    NodeAddress = SourceAddress;      // Set new Node Address (to save only once)
    preferences.begin("nvs", false);
    preferences.putInt("LastNodeAddress", SourceAddress);
    preferences.end();
    Serial.printf("Address Change: New Address=%d\n", SourceAddress);
  }

}

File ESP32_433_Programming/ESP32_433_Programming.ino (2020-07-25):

/*
  Code to program 433 MHz KeyFob

  Transmitter must be connected to ESP32 Pin #19
  Receiver must be connected to ESP32 Pin #15

*/

#include <RCSwitch.h>

unsigned long Key[] = {1000001, 1000002, 1000003, 1000004 };  // Change to individual/random values!
int Keys = sizeof(Key) / sizeof(unsigned long); // Number of keys is calculated atomatically

RCSwitch mySwitch = RCSwitch();


void setup() {

  Serial.begin(115200);
  delay(1000);

  Serial.println("Press 'Send' to start programming or press a key on remote to see the value.");


  mySwitch.enableTransmit(19); // Transmitter is connected to ESP32 GPIO 19
  mySwitch.enableReceive(15);  // RF Receiver is connected to ESP32 GPIO 15

  // Optional set pulse length.
  // mySwitch.setPulseLength(320);

  // Optional set protocol (default is 1, will work for most outlets)
  // mySwitch.setProtocol(2);

  // Optional set number of transmission repetitions.
  // mySwitch.setRepeatTransmit(15);

}

void loop() {
  int i;

  while (!Serial.available()) {    // Receive Key Codes until Send was pressed

    if (mySwitch.available()) {
      long unsigned int value = mySwitch.getReceivedValue();
      Serial.print("Received Key: ");
      Serial.println(value);
      mySwitch.resetAvailable();
    }
  }
  while (Serial.available()) Serial.read();

  Serial.println();

  for (i = 0; i < Keys; i++) {
    Serial.print("Sending Key: ");
    Serial.print(i + 1);
    Serial.print(", Value: ");
    Serial.println(Key[i]);
    Serial.println("Press 'Send' for next Key.");

    while (!Serial.available()) {
      mySwitch.send(Key[i], 24);
      Serial.print(".");
      delay(100);
    }
    Serial.println();

    while (Serial.available()) Serial.read();
  }
  Serial.println("Press 'Send' to start programming or press a key on remote to see the value.");
}

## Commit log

2020-07-26 Avoid delay() and added SetN2kPGN65361 (Seatalk Alarm State)
    [ESP32EvoPilotRemote.ino, RaymarinePilot.cpp]
2020-08-04 Changed TX pin from 2 to 5. Added buzzer (pin 2).
2020-08-04 Changed TX pin from 2 to 5. Addedd buzzer (pin 2). Store/restore last NodeAddress.
    [ESP32EvoPilotRemote.ino]
2020-08-04 Changed TX pin from 2 to 5. Addedd buzzer (pin 2). Store/restore last…
    [ESP32EvoPilotRemote.ino]
2020-08-04 Changed TX pin from 2 to 5. Addedd buzzer (pin 2). Store/restore last NodeAddress.
    [ESP32EvoPilotRemote.ino]
2020-08-04 Changed TX pin from 2 to 5. Addedd buzzer (pin 2). Store/restore last Node Address.
    [ESP32EvoPilotRemote.ino]
2020-09-25 Changed BeepOn() in code to generate beep even if no EV-1 device is found (to allow testing).
2020-09-25 Changed BeepOn() in code to generate beep even if no EV-1 device is found (to alow testing).
2020-10-30 Added KiCAD files
    [ESP32EvoPilotRemote.kicad_pcb, ESP32EvoPilotRemote.sch]
2020-11-05 Version 1.1
    Bbigger terminal (5 mm) and other transistor footprint for easier soldering.
    [ESP32EvoPilotRemote.kicad_pcb, ESP32EvoPilotRemote.sch]
2020-11-05 Version 1.1
    [ESP32EvoPilotRemote.kicad_pcb]
2020-12-16 Version 1.2
    [ESP32EvoPilotRemote.kicad_pcb]
2021-08-29 Switch off WiFi and BT completely.
2022-02-05 Use new ESP32-API function name "esp_efuse_mac_get_default(chipid);"
